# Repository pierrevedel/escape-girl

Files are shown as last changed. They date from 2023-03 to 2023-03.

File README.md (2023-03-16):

# ESCAPE GIRL - l'escape game sur la sensibilisation au harcelement sexuel

Escape girl est un outil pédagogique destiné à un public d'adolescents sous forme d'escape game inspiré d'une [campagne de communication gouvernementale de 2016](https://arretonslesviolences.gouv.fr/je-suis-professionnel/outils-de-communication) diffusée dans les transports en commun. Les affiches de cette campagne montrent le cheminement de pensée des 3 acteurs d'un harcèlement (l'auteur, la victime et le temoin) sous forme de plan de métro.
Le plateau de jeu pédagogique reprend le fond et la forme de cette campagne. Le jeune sensibilisé doit retrouver quel acteur pense quoi en repositionnant les étiquettes. Il n'y a qu'une seule combinaison qui affichera la clef complète de l'escape game (un chiffre qui permet de passer à l'étape d'après).

boardgame]

## clef affichée
La clef de ce enigme est un 5. le segment horizontal median s'affiche dès l'alimentaton du système. Ce plateau n'est qu'une enigme de l'escape complet. les autres enigmes donnent les chiffres 7 et 0 : 750€, le montant de l'amende pour agression. (on peut aussi proposer le 3020, numéro d'appel des élèves harcelés à l’école )

## contenu numérique
- un plateau de jeu (épaisseur 22mm) et des étiquettes (épaisseur 15mm) à usiner d'apres un modèle 3d (.step)
- une infographie à graver au laser d'apres un modèle vectoriel (.svg)
- un schéma électronique à cabler ou faire fabriquer le pcb à ouvrir avec kicad (.kicad_sch & .kicad_pcb)
- un couronne pour l'afficheur numérique à fabriquer sur imprimante 3d d'après modèle 3d (.stl)

## composants électroniques
la référence donné est celle du revendeur gotronic

| composant  | conditionnement | quantité | référence |
| --- | --- | --- | --- |
| Connecteurs sub-D mâles Droit 9 contacts | 1 | 12 | 08105 |
| Connecteurs sub-D femelle Droit 9 contacts | 1 | 12 | 08110 |
| vis tête fraisée inox M3 10 mm  | 10 | 3 | 11626 |
| ecrou M3  | 1 | 24 |  |
| Leds rouges LED5RL leds éco 5 mm | 10 | 1 | 03025 |
| Clip 5 mm 115SC neoprene | 1 | 4 | 03118 |
| Résistance carbone 1W 68Ω | 1 | 5| 04222 |
| Résistance carbone 1W 120Ω  | 1 | 1 | 04225 |
| Afficheur SC08-11R 20 mm rouge CC | 1 | 1 | 03176 |
| Platine à connecteur micro-USB B 2586 | 1 | 1 | 34786 |
| vis auto-taraudeuses 2,2x6,5mm  | 10 | 1 | 11850 |
| Inverseur à glissière miniature | 1 | 1 | ESP101 |
| Connecteur NSK254-4C mâle coudé 4 cts | 1 | 2 | 48712 |
| Boîtier NSK254-4B femelle pour 4 cts | 1 | 2 | 48722 |
| contact NSK254-0 pour boîtier NSK254 | 10 | 2 | 48724 |
| Assortiment FCS60 fil souple - 60 m  | 1 | 1 | 08956 |
| batterie avec cable micro USB-B (max 92x60x12mm) | 1 | 1 |  |

## outillage nécessaire
- fraiseuse à commande numérique
- laser à commande numérique
- pince à sertir necessaire pour les connecteurs NSK254
- pince à dénuder
- pince coupante
- poste à souder l'étain
- embout à chanfreiner que les vis à têtes fraisées affleurent la surface du tableau de bord
- pistolet à colle pour maintenir les cables
- scratch autocollant pour maintenir la batterie

## maître d'ouvrage
l'escape game complet est organisé par [aroeven occitanie](https://aroeven-occitanie.fr/)

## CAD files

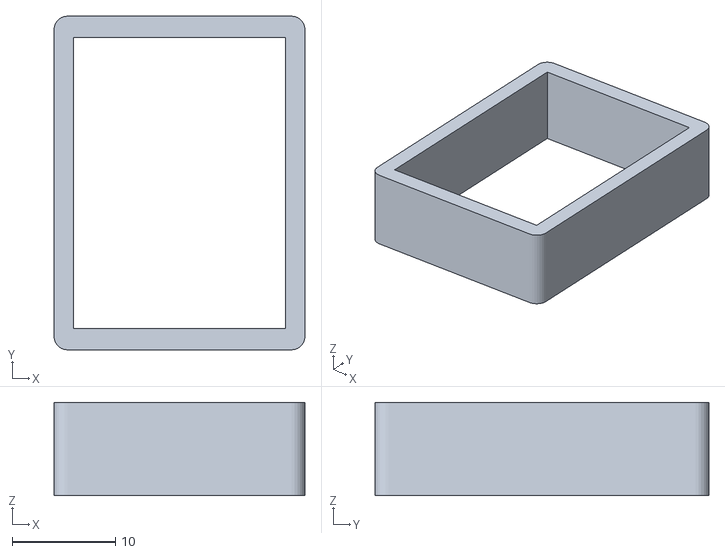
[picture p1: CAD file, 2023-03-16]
couronne/escape-girl_afficheur-couronne.stl
24.3 x 32.3 x 9.00

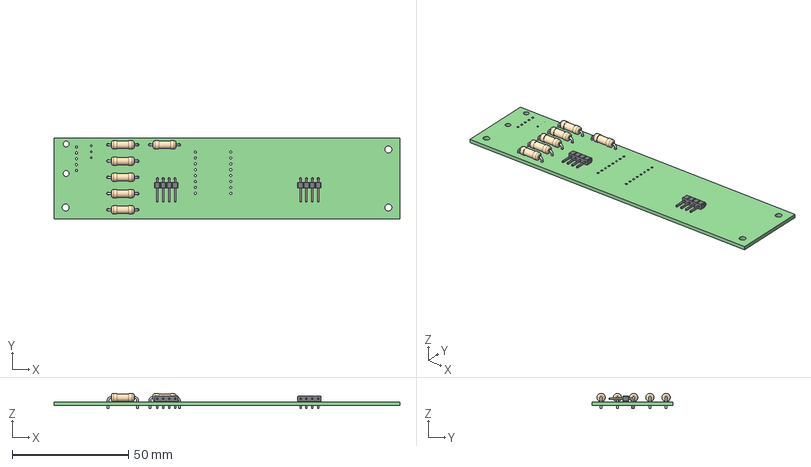
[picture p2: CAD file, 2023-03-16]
pcb/escape_girl_pcb.step
149.0 x 35.0 x 6.60 mm
escape_girl PCB

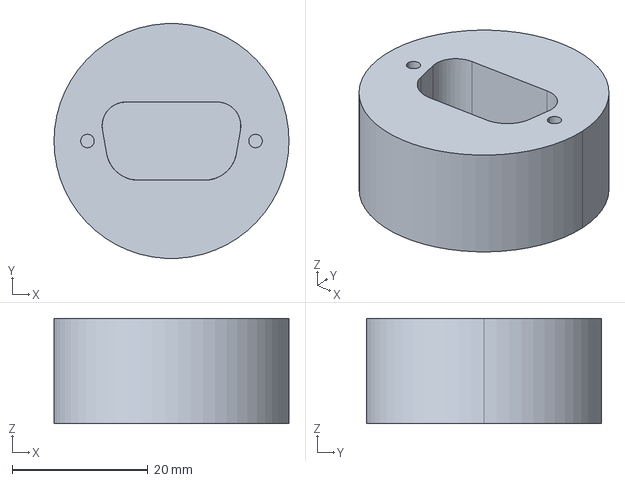
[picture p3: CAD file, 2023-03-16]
plateau/escape-girl_etiquette-commentaire.stp
34.7 x 34.6 x 15.5 mm

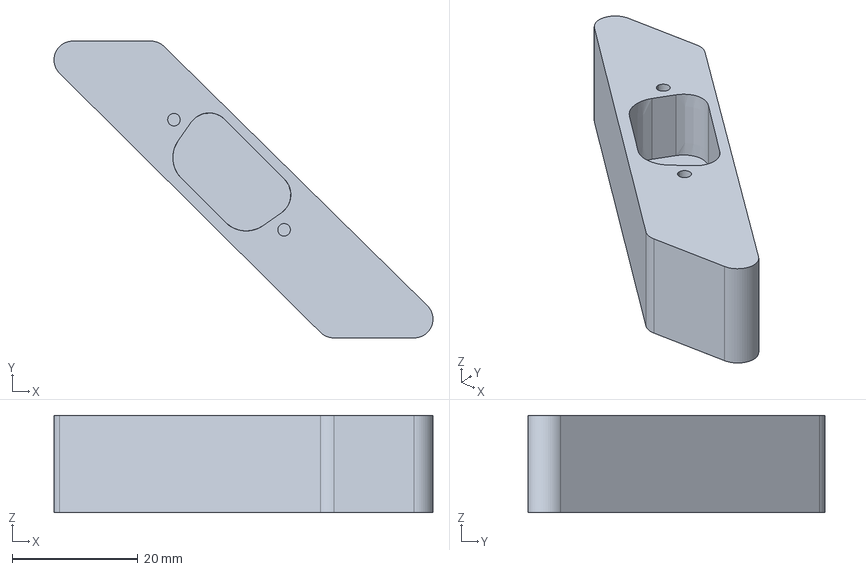
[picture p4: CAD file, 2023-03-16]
plateau/escape-girl_etiquette-acteur.stp
60.4 x 47.3 x 15.5 mm

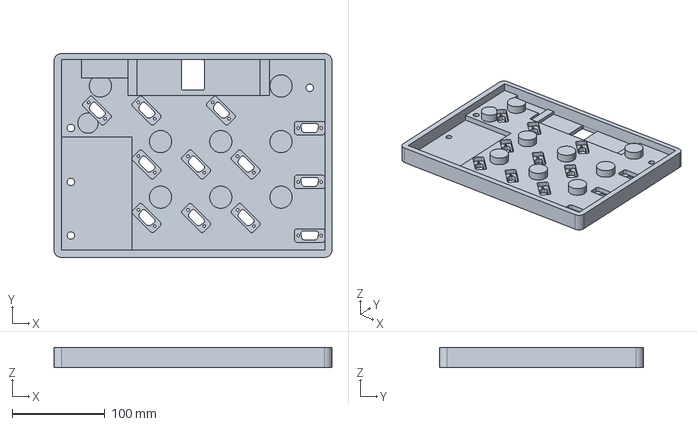
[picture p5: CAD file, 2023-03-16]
plateau/escape-girl_plateau.stp
300.0 x 220.0 x 22.0 mm

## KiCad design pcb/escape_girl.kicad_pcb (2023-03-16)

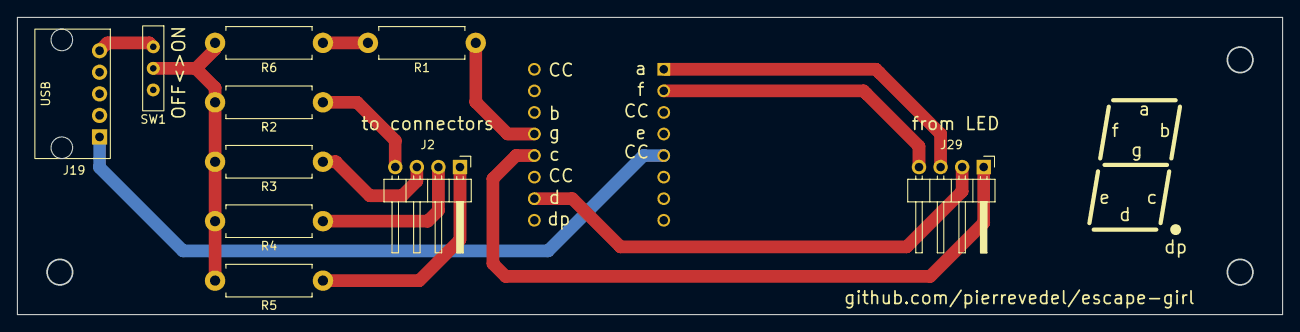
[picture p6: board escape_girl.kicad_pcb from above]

Board: 2 copper layers, 149.0 x 35.0 mm, 11 parts (1 on the bottom side), 13 nets.

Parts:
DS1: SC08-11SRWA; SC08-11SRWA_DIPS1524W80P254L2770H865Q16N
J2, J29: Conn_01x04; PinHeader_1x04_P2.54mm_Horizontal
J19: USB_B_Micro; USB_micro-B_polulu-2586
R1: 120; R_Axial_DIN0411_L9.9mm_D3.6mm_P12.70mm_Horizontal
R2, R3, R4, R5, R6: 68; R_Axial_DIN0411_L9.9mm_D3.6mm_P12.70mm_Horizontal
SW1: SW_SPDT; SW_slide_SPDT_10x2.5mm

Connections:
+5V: J19.1 (VBUS), SW1.3 (C)
GND: DS1.5 (COMMON_CATHODE_2), J19.5 (GND)
unnamed: DS1.1 (ANODE_A), J29.3
unnamed: DS1.2 (ANODE_F), J29.4
unnamed: DS1.10 (ANODE_D), J29.2
unnamed: DS1.12 (ANODE_C), J29.1
unnamed: DS1.13 (ANODE_G), R1.1
unnamed: J2.1, R5.1
unnamed: J2.2, R4.1
unnamed: J2.3, R3.1
unnamed: J2.4, R2.1
unnamed: R1.2, R6.1
unnamed: R2.2, R3.2, R4.2, R5.2, R6.2, SW1.2 (B)
